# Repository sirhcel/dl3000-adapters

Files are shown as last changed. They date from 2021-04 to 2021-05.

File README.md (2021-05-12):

# Banana Jack and BNC Adapters for RIGOL DL3000 Electronic Loads

## Overview

This project is about banana jack and BNC adapters for RIGOL's DL3000 series
electronic loads. There are already adapters for narrower binding posts (like
BK Precision, ...) but I did not find any for the 39 mm pitch of the RIGOL
DL3000 series.

These adapters are meant for conveniently feeding a few amperes - not for high
current applications.

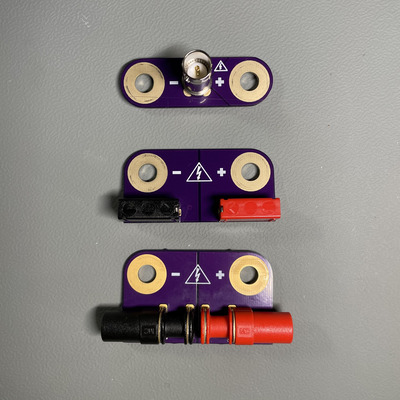
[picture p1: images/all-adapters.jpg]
Adapters All Adapters


## Variants and Bills of Material

### BNC Adapter

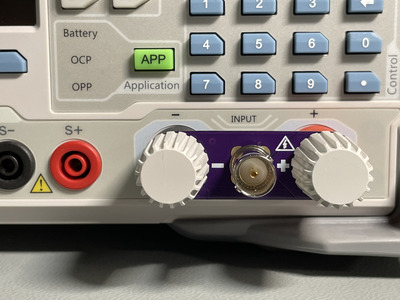
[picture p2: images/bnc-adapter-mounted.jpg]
BNC Adapter

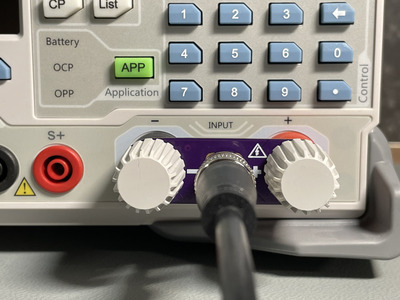
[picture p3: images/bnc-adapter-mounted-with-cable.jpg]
BNC Adapter with Cable


The BNC adapter has a pretty standard footprint. So you should be able to find
a suitable replacement from your preferred distributor. Information on
replacement parts welcome.

* 1 PCB
    * KiCad design files form this repository
    * [Gerber and drill files](orders/dl3000-bnc-adapter-1.0-85dbc15.zip)
    * [Or just order it from OSH Park](https://oshpark.com/shared\_projects/MOcX6Gow)
* 1 [BNC connector](https://www.reichelt.de/steckverbinder-bnc-75-ohm-gerade-rnd-205-00437-p194660.html)

### Banana Jack Adapters

There are two board variants for sourcing the connectors from different
distributors.

#### PB4 Banana Jack Adapter

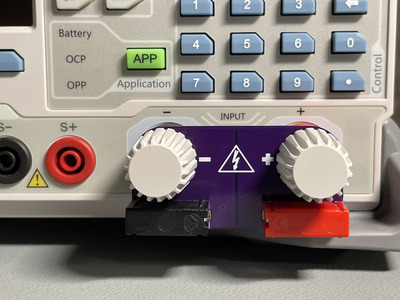
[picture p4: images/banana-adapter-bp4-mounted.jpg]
PB4 Banana Jack Adapter

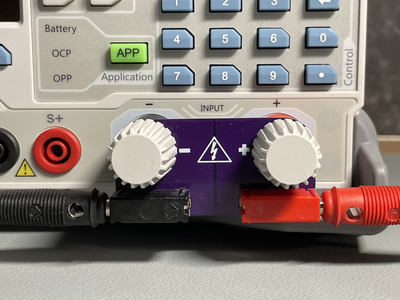
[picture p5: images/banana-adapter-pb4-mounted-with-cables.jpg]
PB4 Banana Jack Adapter with Cable


* 1 PCB
    * KiCad design files from this repository
    * [Gerber an drill files](orders/dl3000-banana-adapter-1.0-85dbc15.zip)
    * [Or just order it from OSH Park](https://oshpark.com/shared\_projects/gLsNtQ88)
* 1 connector Hirschmann Test and Measurement
  [PB4 red](https://www.reichelt.de/leiterplattenbuchse-4-mm-rot-pb-4-rt-p76865.html)
* 1 connector Hirschmann Test and Measurement
  [PB4 black](https://www.reichelt.de/leiterplattenbuchse-4-mm-schwarz-pb-4-sw-p13998.html)

#### 73099 Banana Jack Adapter

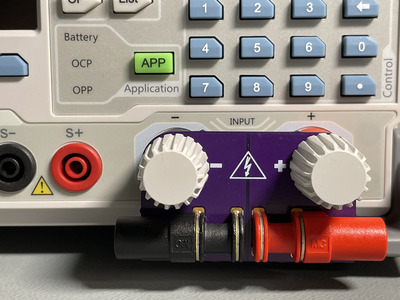
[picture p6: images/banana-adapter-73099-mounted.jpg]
73099 Banana Jack Adapter

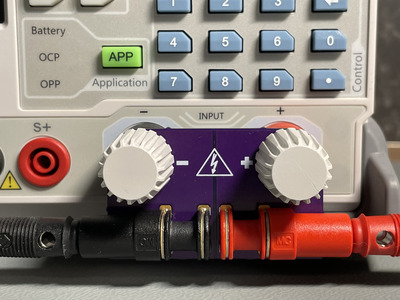
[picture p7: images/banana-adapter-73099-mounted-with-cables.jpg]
73099 Banana Jack Adapter with Cables


* 1 PCB
    * KiCad design files form this repository
    * [Gerber and drill files](orders/dl3000-banana-adapter-73099-1.1-8dd8051.zip)
    * [Or just order it from OSH Park](https://oshpark.com/shared_projects/TMnpJrJW)
* 1 connector Pomona [73099
  red](https://www.digikey.com/en/products/detail/pomona-electronics/73099-2/10483465)
* 1 connector Pomona [73099
  black](https://www.digikey.com/en/products/detail/pomona-electronics/73099-0/10483460)

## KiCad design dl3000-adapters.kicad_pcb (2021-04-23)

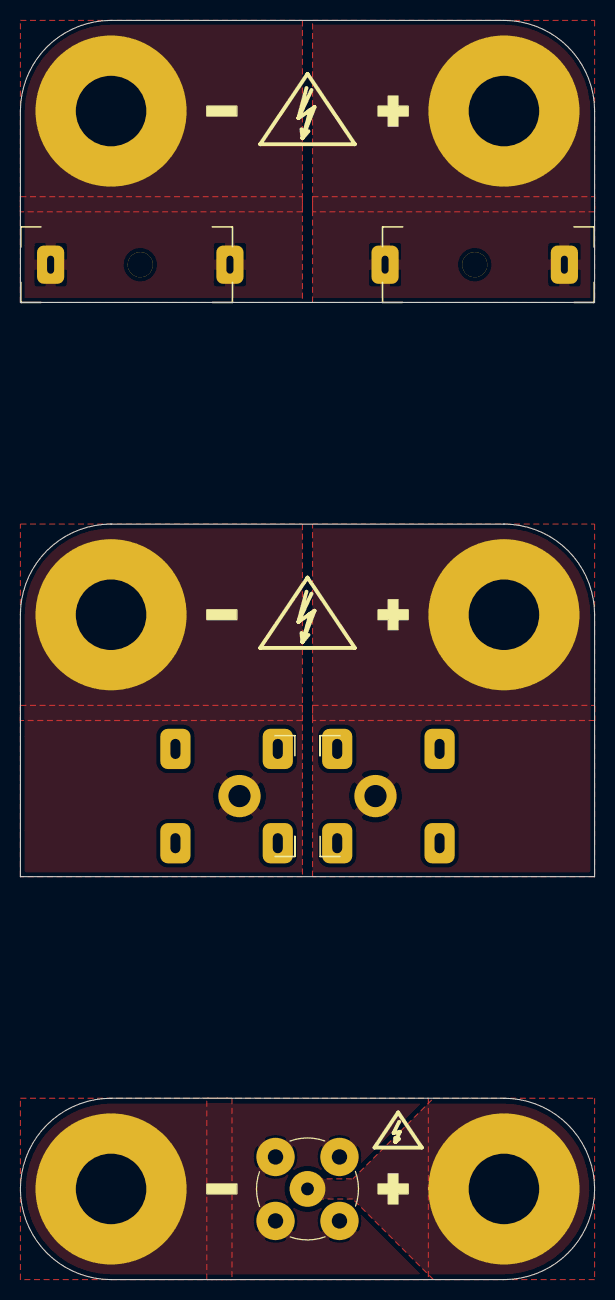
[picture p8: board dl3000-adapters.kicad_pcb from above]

Board: 2 copper layers, 57.0 x 125.0 mm, 8 parts (0 on the bottom side), 6 nets, no tracks yet.

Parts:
J1, J3: Banana Jack; Hirschmann_SKS_PB4
J2: BNC; BNC_TEConnectivity_1478204_Vertical
J4, J5: Banana Jack; Pomona_73099
TP1, TP2, TP3: Binding Posts; TestPoint_2Pads_D15.0mm_Drill7.0mm_RIGOL_DL3000_Binding_Pos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

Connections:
/BANANA_73099+: J5.1, TP3.2
/BANANA_73099-: J4.1, TP3.1
/BANANA_PB4+: J3.1, TP1.2
/BANANA_PB4-: J1.1, TP1.1
/BNC+: J2.1, TP2.2
/BNC-: J2.2, TP2.1

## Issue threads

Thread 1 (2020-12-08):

Multi-use footprint

gcormier, 2020-12-08:
I am designing a variant which can use a more-common footprint in North America. Both Harwin ( https://www.digikey.ca/en/products/detail/harwin-inc/M3498-99/4953082 ) and Cinch Connectivity (https://www.digikey.ca/en/products/detail/cinch-connectivity-solutions-johnson/105-0752-001/5887 ) have similar jacks that use the same footprint.

I could do a separate footprint altogether, or, add a 3rd hole to your existing design (removing your center pin, unsure on the point of that?) so it could accommodate all of these in 1 board. Any thoughts?

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

We would need to remove the circle pad pointed to.

sirhcel, 2020-12-09:
Thanks for your feedback!

> I could do a separate footprint altogether, or, add a 3rd hole to your existing design (removing your center pin, unsure on the point of that?) so it could accommodate all of these in 1 board. Any thoughts?

Having the option to fit either connector would make the board more versatile. So I would opt for the 3rd hole.

The Hirschmann connector offers a hole for additionally screwing it to the board. Looking at your image and a board on my desk, it looks like I have messed up the drill diameter. The one in the board is actually way to small. So please go ahead and remove the hole. I've used the connectors on several test jigs and never felt like a screw was needed.

gcormier, 2020-12-10:
Okay I submitted a PR. I've also ordered some PCB's so I can take a picture of them over Christmas once they arrive!

sirhcel, 2020-12-14:
Awesome! Thank you very much! Let's have the conversation continued at #2.

gcormier, 2020-12-24:
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

So I've found a CalTest version that is quite big. It would mean increasing the PCB size.

What are your thoughts?

sirhcel, 2020-12-26:
The connector from CalTest is indeed a bit clunky. And I'm a bit afraid of the big lever it introduces.

DigiKey does not seem to have a big selection of PCB-mount banana plug sockets. What about another distributor?
* Newark seems to have the [Hirschmann 973582100 in stock](https://www.newark.com/hirschmann-testmeasurement/973582100/test-socket-pcb-4mm-black/dp/06WX5874) in the US and Canada. Though they are sold only in packs of five. I see that this might not be convenient for building up just a single adapter.
* Newark also offers the [DELTRON 571-0100-01](https://www.newark.com/deltron-components/571-0100-01/test-point-socket-pcb-4mm-10a/dp/93K4533) which is sold individually. And it looks that we could use a multi-part footprint at a first glance.

I also searched searched through DigiKeys selection and apart of the CalTest connector I only found two connectors from Pomona which are quite pricy:
* The [73099](https://www.digikey.ca/en/products/detail/pomona-electronics/73099-2/10483465) as an angled variant which likelky requires increasing the PCB.
* The [73096](https://www.digikey.ca/en/products/detail/pomona-electronics/73096-2/10483466) as a vertical variant. This is an interesting alternative to me in case you have sitting another instrument right next to your DL3000 and a plug in the angled connector forms quite a big "cantilever".

So what about working aout a joint-footprint for the original Hirschmann and the DELTRON connector? I will give the vertical connector from Pomona some thoughts, may be it still fits on the same PCB as well.

gcormier, 2020-12-28:
I think the 73099 from Pomona would be the preferred option for North America. It is stocked by both Digikey and Mouser which are probably the most popular distributors here.

sirhcel, 2021-01-05:
Alright. Then we should be able to make another multi footprint board for the Pomona 73099. It looks like we have to slightliy increase the board "downwards" to keep the clearance to the DL3000 binding posts.

Could you add this footprint to the banana jack board? I will do the housekeeping and update the manufacturing data and the project as OSH Park.

gcormier, 2021-01-05:
Sure I will design the footprint and add it.

On Tue, 5 Jan 2021 at 05:43, Christian Meusel <notifications@github.com>
wrote:

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

gcormier, 2021-01-06:
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

So, the height will definitely need to increase slightly.

I've put each in a different position to get your opinion. Either of these, the connector is hanging off the side of the board. The left position keeps the width of the board the same. The right position would require us to increase the width of the PCB.

I'll send a PR so you can get the files and play around with the position.

sirhcel, 2021-01-09:
Thanks for the PR! I would place the Pomona jacks back to back and - after playing around with them - on a separate board. In this position their solder joints should also not interfere with the rubber feet of the DL3000 case.

I noticed that the lower left mounting PTH (on J5 in https://github.com/sirhcel/dl3000-adapters/issues/1#issuecomment-755452604) is slightly offset. Once I started looking at the datasheet in detail, I would go for rectangular/oval PTHs. This would allow to insert the mounting pins completely and place the plastic housing of this jack flat onto the PCB.

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

You could look at the updated footprint and new board [here](https://github.com/sirhcel/dl3000-adapters/blob/d006e15b4c36e5e3f11c739fdd69e3a85d045e80/dl3000-adapters.kicad_pcb). Could you please cross-check footprint and placement?

sirhcel, 2021-01-09:
After fixing my remote for your PR, I added my update to #3 as well.

sirhcel, 2021-05-12:
I ordered some boards as of https://github.com/sirhcel/dl3000-adapters/issues/1#issuecomment-757332319 and the new footprint works out. Let's go with individual boards for the different footprints then.

Closed 2021-05-12.

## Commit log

2019-12-21 Add initial schematic and footprints
    [dl3000-posts.sch]
2019-12-23 Rename to DL3000 Adapters
    [dl3000-adapters.sch]
2019-12-23 Add first board layouts
    [dl3000-adapters.kicad_pcb]
2019-12-23 Add information on bottom silk screen
    [dl3000-adapters.kicad_pcb]
2019-12-23 Add comments to schematic and board
    [dl3000-adapters.kicad_pcb, dl3000-adapters.sch]
2019-12-23 Add high voltage symbols to top silk screen
    This includes deriving the very small and ultra small symbol from the
    copper layer variant already present in the library.
    [dl3000-adapters.kicad_pcb]
2019-12-23 Add data for ordering boards at OSH Park
2020-01-23 Add README.md with BOM
2021-01-06 pomona footprint
    [dl3000-adapters.kicad_pcb, dl3000-adapters.sch]
2021-01-09 Fix position of lower left mounting PTH
2021-01-09 Add corner marks to silkscreen
2021-01-09 Use rectangular PTHs for mounting brackets
    These PTHs have some extra spacing in the vertical direction for
    allowing the connector pins to get inserted completely and the plastic
    case could sit right on top of the PCB. The rest rings got quite large
    allowing beefy solder joints to take the mechanical stress.
2021-01-09 Fix rest ring and mounting hole for PB4 footprint
2021-01-09 Add separate board for Pomona jacks
    It would be too much of a hassle to have both banana jack footprints
    overlap on the same board.
    [dl3000-adapters.kicad_pcb, dl3000-adapters.sch]
2021-01-09 Increase clearance on BNC board to 0.5 mm
    This adds some extra margin to the clearance of 0.4 mm I found on
    https://www.mikrocontroller.net/articles/Leiterbahnabst%C3%A4nde#Mindestkriechstrecken_bei_Leiterplatten
    for the input voltage rating of 150 V.
    [dl3000-adapters.kicad_pcb]
2021-04-23 Remove references from 73099 silk screen
    [dl3000-adapters.kicad_pcb]
2021-04-23 Add data for ordering 73099 board at OSH Park
